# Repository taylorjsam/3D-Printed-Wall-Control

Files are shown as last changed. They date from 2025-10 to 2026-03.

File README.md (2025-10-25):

🛠️ Custom Tool Hangers for Wall Control Pegboard

This repository contains a growing collection of 3D-printable custom tool holders designed specifically for Wall Control pegboard systems (metal pegboard with slotted mounting holes). These hangers are tailored for various tools and accessories — from calipers and screwdrivers to highly specific tool geometries.

⸻

📁 Folder Structure

Metal Small WC Hook Hangers/

These models are designed to use the small metal Wall Control hooks (10-HS-001) that are inserted into the back of the print. The holder portion is 3D-printed and provides the form-fitting rest or clamp for the specific tool:
	•	Ideal when you want the strength and reliability of steel engagement with the board.
	•	Faster print time since hooks are not printed.
	•	Just insert the metal hook into the designated cavity in the print and it should snap into place.

These are perfect for medium to heavy-weight tools.

⸻

Printed Snap Hook Hangers/

These models are designed to use the 3D-printable hook inserts, allowing for fully printed hangers:
	•	Current Version: Gen 4
	•	Toolless snap-in installation.
	•	Injection slot included for glue if additional reinforcement is desired.
	•	Zero-clearance fit to minimize movement once mounted.
	•	Optimized to align tightly within the Wall Control slot geometry.

These are perfect for lightweight to medium-weight tools where full-print integration makes sense.

⸻

🧰 Tool Compatibility

Each tool holder is generally named for the tool it fits, such as:
	•	Park Tool HMR-4
	•	Olsa Flat Pick 3pc
	•	Vessel Megadora 6pc
	•	Caliper Holder (generic)
	•	Wera Hex Plus Allen Set
	•	Knipex 250mm Pliers Wrench

Some holders are generic and multipurpose (e.g., caliper or utility hangers), while others are precision-contoured for exact fits based on STL scans or manual measurements.

⸻

🖨️ Print Recommendations
	•	Primary Material: PETG (Alternatives: PLA+ or ABS)
	•	Nozzle: 0.4 mm
	•	Layer Height: 0.2 mm
	•	Infill: 25%
	•	Walls (Perimeters): 4
	•	Top/Bottom Solid Layers: 4
	•	Supports: Not required (all parts are designed to be support-free)
	•	Orientation: All files are provided in the correct print orientation, but can be rotated if needed.

⸻

🔩 Assembly Notes
	For Printed Snap Hook versions:
	•	Insert the snap hooks into the back of the tool holder — they lock in place via compression and geometry. (Once inserted hook is NOT removable from holder)
	•	Optionally inject a small amount of superglue or epoxy through the glue port.
	•	Thumb tab at the bottom allows for easy installation and removal from wall.
	For Metal WC Hook versions:
	•	Simply press the Wall Control metal hook into the back cavity until fully seated.
	•	Hook is removable but holders are designed to allow installation onto the wall without removal
	Note about warping: On some printers or with certain materials, the longer pieces may be prone to warping. To address this, I’ve included hook mounts both near the center and near the edges. Only two hooks are recommended for these pieces with 4 placement options. If no warping is present, I recommend using the outer mounts as they provide slightly stronger support. However, if any warping is observed, use the inner mounts instead. Attempting to use the outer mounts with a warped piece may shear off the hooks, as they cannot be inserted straight when the part is bent.

⸻

🙌 Contributions

I’m actively refining existing holders and designing new ones as I add tools to my collection. The Gen 4 snap hook system is the most current and reliable release — featuring tight tolerance fits, toolless installation, and optional glue injection points for reinforcement. I am also adding need tools as I acquire them and as I have time.

Got a tool you’d like a hanger for? Submit a request or fork the repo and contribute your own design! If you’re submitting a pull request, please make sure to test the holder with the actual tool first — the goal is to keep all shared designs accurate, functional, and ready for real-world use without modification.

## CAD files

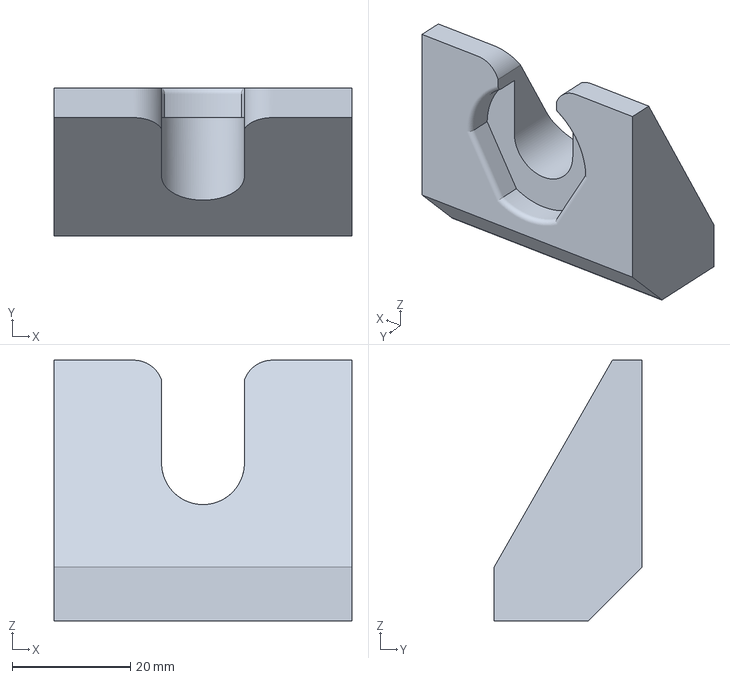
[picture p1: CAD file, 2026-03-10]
Gen 4 Hook.3mf
50.4 x 25.0 x 44.1 mm

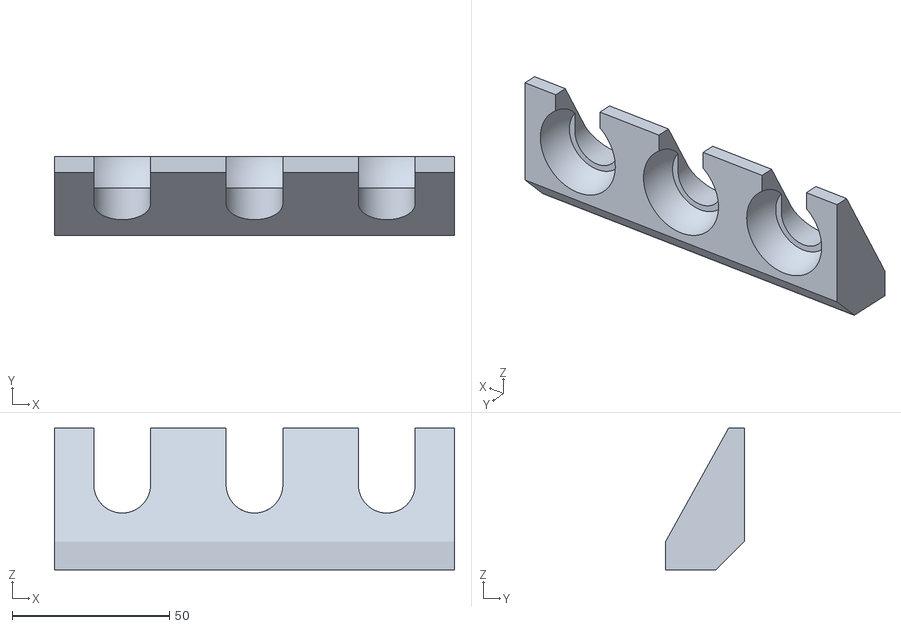
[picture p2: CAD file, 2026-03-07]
Printed Snap Hook Hangers/DeWalt/DeWalt 3pc Chisel.stl
127.0 x 25.0 x 45.1

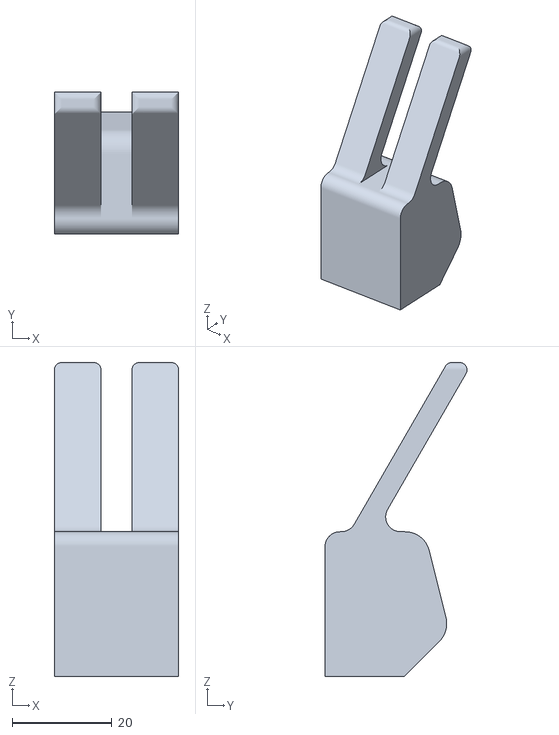
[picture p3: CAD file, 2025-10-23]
Printed Snap Hook Hangers/Doyle/Doyle soft-jaw Pliers PH.stl
25.0 x 28.5 x 63.1

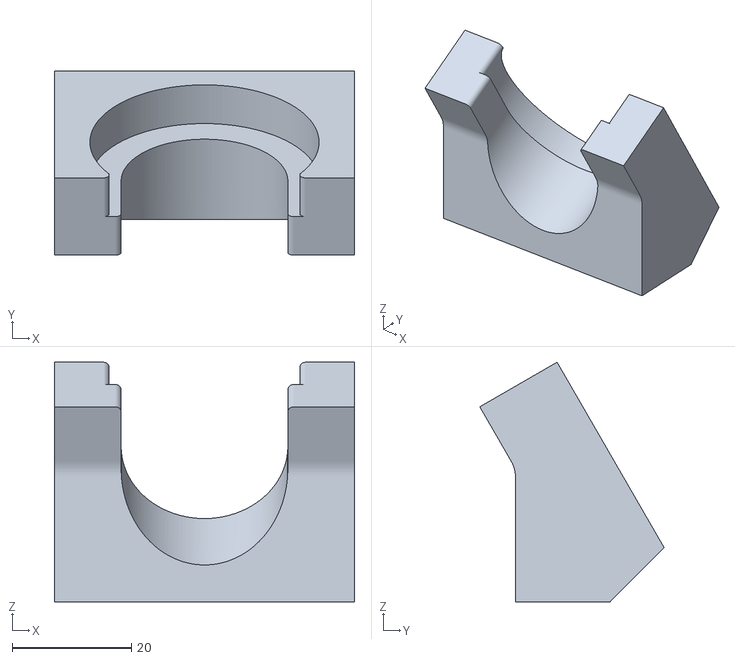
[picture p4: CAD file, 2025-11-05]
Printed Snap Hook Hangers/Engineer/Engineer DR-54 v1 PH.stl
50.4 x 31.0 x 40.3

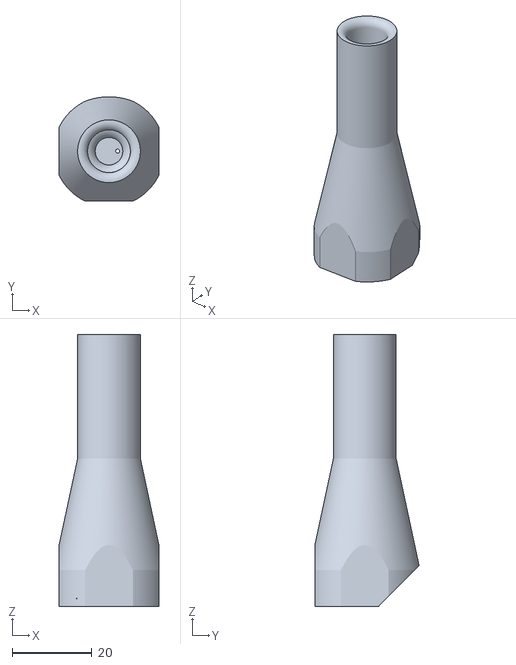
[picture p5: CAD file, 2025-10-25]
Printed Snap Hook Hangers/Finish Line/Finish Line Grease Gun PH.stl
25.0 x 26.1 x 68.1

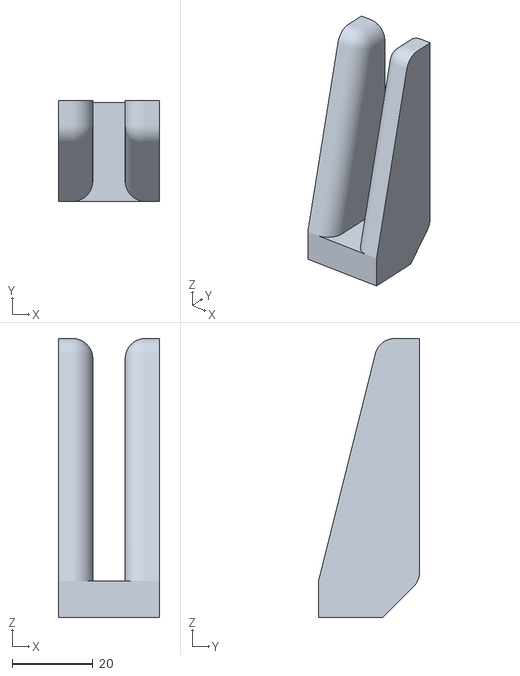
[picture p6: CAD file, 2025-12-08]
Printed Snap Hook Hangers/Generic/Adjustable Wrenches/Adjustable Wrench 8mm (vert) PH.stl
25.0 x 25.0 x 69.1

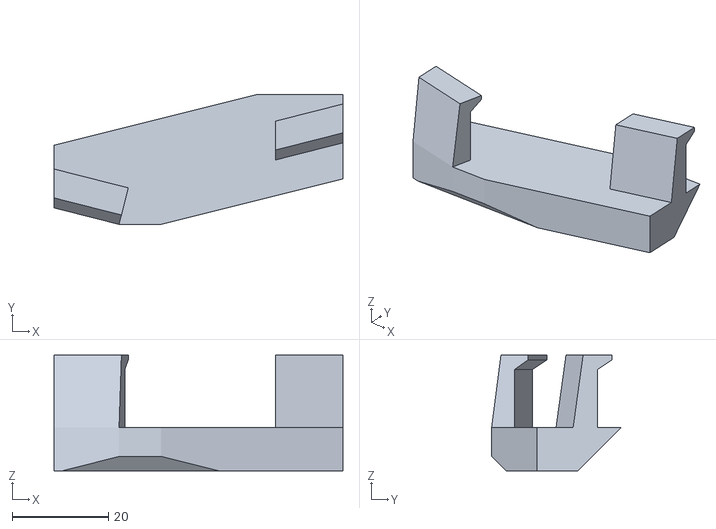
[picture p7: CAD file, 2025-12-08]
Printed Snap Hook Hangers/Generic/Calipers (deep) PH.stl
60.0 x 26.9 x 24.1

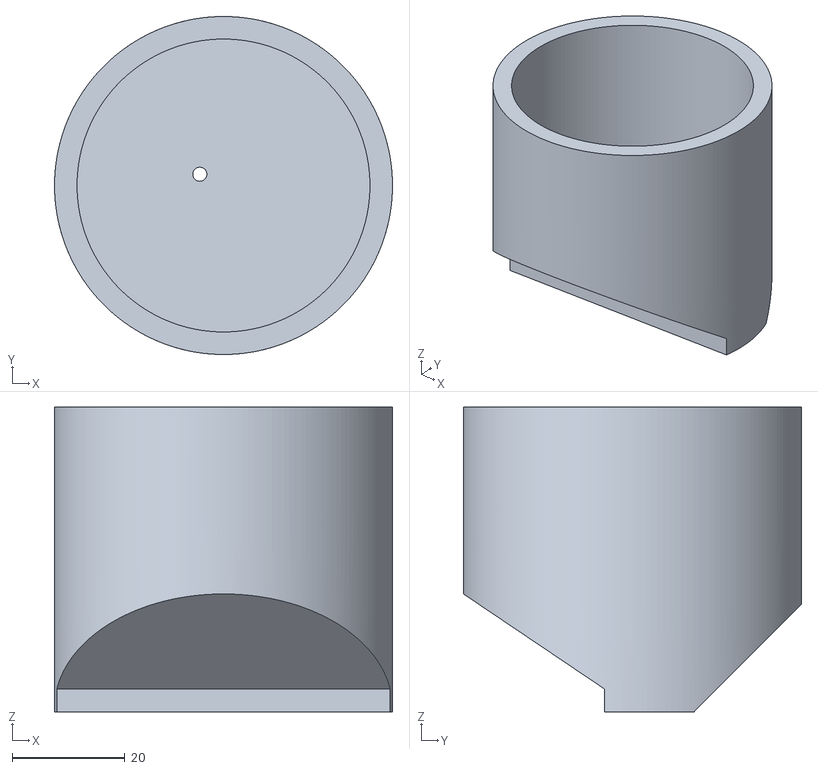
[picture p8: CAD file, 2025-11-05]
Printed Snap Hook Hangers/Generic/Hammers (hold by head face)/51.5mm Hammer PH.stl
60.0 x 60.0 x 54.1

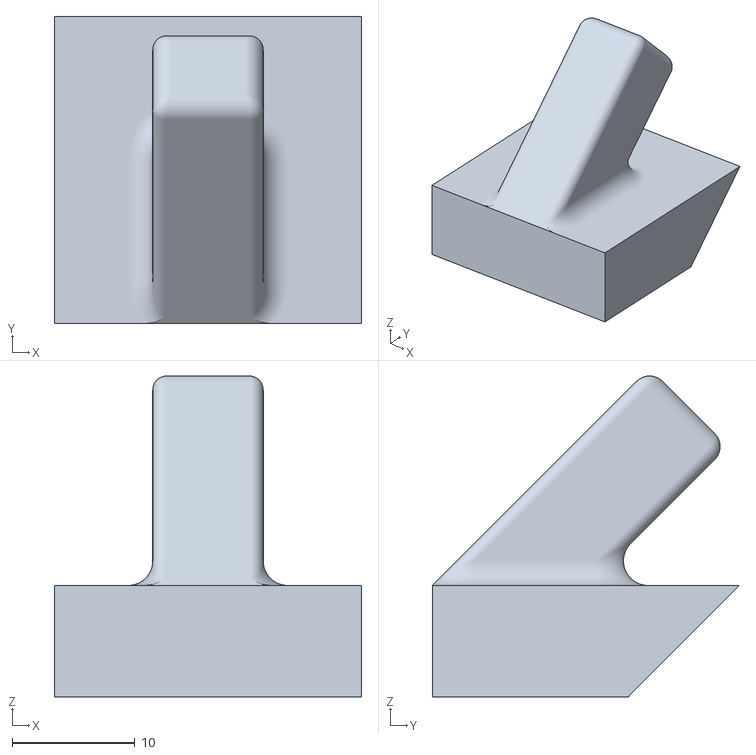
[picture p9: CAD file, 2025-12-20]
Printed Snap Hook Hangers/Generic/Socket Drive Accessories/1x 3:8 Drive Male.stl
25.0 x 25.0 x 26.1

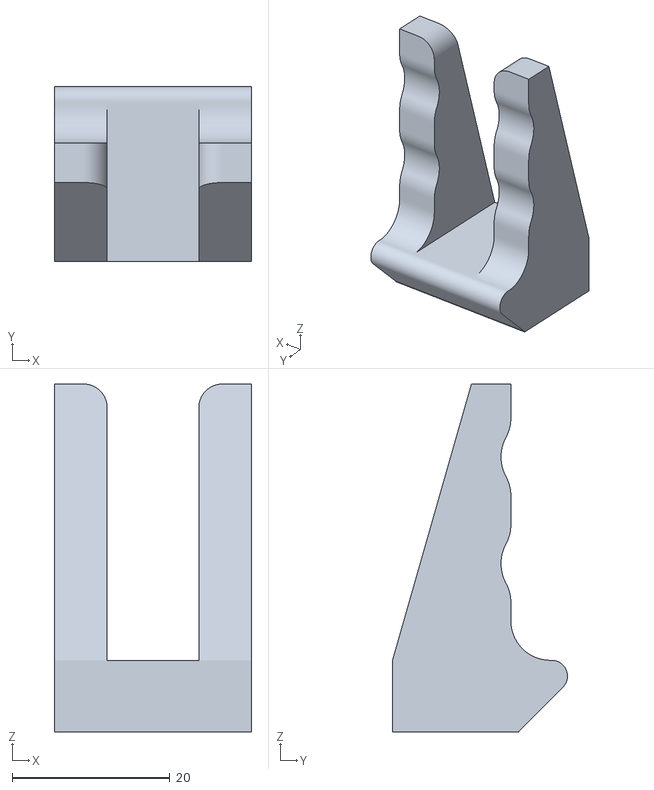
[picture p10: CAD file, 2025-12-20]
Printed Snap Hook Hangers/Icon/Icon Long Nose Slip Joint Pliers.stl
25.0 x 22.2 x 44.1

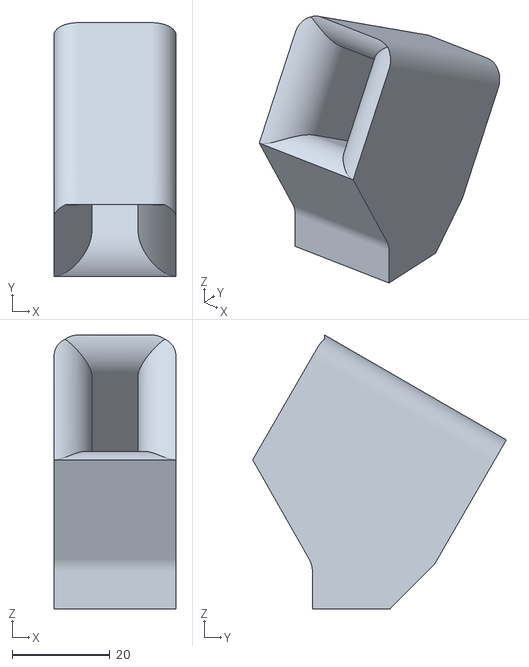
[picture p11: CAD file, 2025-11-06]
Printed Snap Hook Hangers/Igance/Igance P6 Pro (vert) PH.stl
25.0 x 52.0 x 56.2

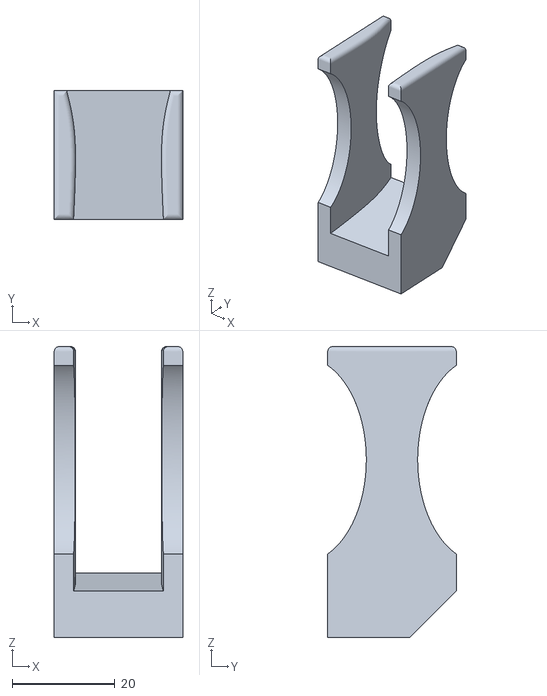
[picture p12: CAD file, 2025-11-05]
Printed Snap Hook Hangers/Knipex/Knipex 2612200 (vert) PH.stl
25.0 x 25.0 x 56.6

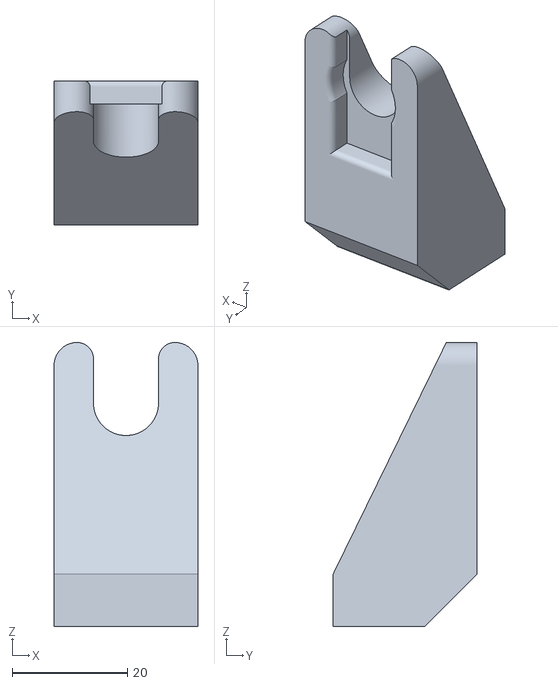
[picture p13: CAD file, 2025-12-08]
Printed Snap Hook Hangers/Milwaukee/Milwaukee Hamerdrill Handle PH.stl
25.0 x 25.0 x 49.3

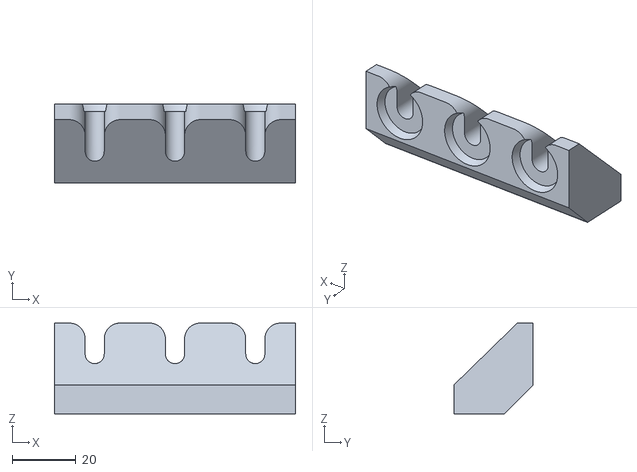
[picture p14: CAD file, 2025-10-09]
Printed Snap Hook Hangers/Olsa/Olsa Flat Pick 3pc PH.stl
75.8 x 25.0 x 28.6

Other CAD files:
Printed Snap Hook Hangers/Park Tool/Park Tool CT-3 (vert) PH.stl
Printed Snap Hook Hangers/PB Swiss/PB Swiss 1255 MR PH.stl
Printed Snap Hook Hangers/Pedro's/Pedros Cable Cutters (vert)PH.stl
Printed Snap Hook Hangers/Rock Shox/Rock Shox Shock Pump SH.stl
Gen 4 Hook.stl
Old Hooks/Gen 3 Hook.stl
Printed Snap Hook Hangers/Gedore/Gedore sg Ratcheting Screwdriver.stl
Printed Snap Hook Hangers/Generic/Adjustable Wrenches/Adjustable Wrench 10mm (vert) PH.stl
Printed Snap Hook Hangers/Generic/Adjustable Wrenches/Adjustable Wrench 9mm (vert) PH.stl.stl
Printed Snap Hook Hangers/Generic/Angle Grinder (wrench) PH.stl
Printed Snap Hook Hangers/Generic/Angle Grinder Disc Holder.stl
Printed Snap Hook Hangers/Generic/Bic Ligher Holder PH.stl
Printed Snap Hook Hangers/Generic/Calipers (shallow) PH.stl
Printed Snap Hook Hangers/Generic/Flat Hook 25mm at 45deg PH.stl
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

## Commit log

2025-10-04 First dump of completed files
    [Holder 10mm (chamfered) v2.stl, Holder 10mm (cylinder) v2.stl, Holder 10mm (flat) v2.stl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]
2025-10-05 snap hooks dump
    [Generic Calipers PH.stl, Park Tool CC-3.2 PH.stl]
2025-10-06 10/5 dump
    [Park Tool PW-3 WC.stl, Park Tool TM-1 PH.stl]
2025-10-07 dump 10/6
    [Park Tool 1in Hex Holder.stl, Park Tool CCP-22.stl, Park Tool CCW-5.stl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]
2025-10-07 organizing + 10/6 dump p2
    [Generic Calipers PH.stl, Park Tool 1in Hex Holder PH.stl, Park Tool CCW-5 PH.stl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]
2025-10-08 Gen 3 plastic hook updates
    [Generic Calipers PH.stl, Park Tool 1in Hex Holder PH.stl, Park Tool CC-3.2 PH.stl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]
2025-10-09 10/8 dump
    [Olsa Flat Pick 3pc PH.stl, SK 8in Shears.stl, Spoke Pick Holder PH.stl]
2025-10-09 10/8 fixes
    [Olsa Flat Pick 3pc PH.stl, SK 8in Shears.stl]
2025-10-10 10/9 dump/updates
    [Calipers PH.stl, Flat Hook 25mm at 45deg PH.stl, Generic Calipers PH.stl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]
2025-10-16 Gen 4 Hook + organization + readme
    [Calipers PH.stl, Flat Hook 25mm at 45deg PH.stl, Gen 3 Hook.stl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]
2025-10-18 10/17 dump + PH organization
    [Bic Ligher Holder.stl, Olsa Flat Pick 3pc PH.stl, PB Swiss 4pc PH-PZ.stl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]
2025-10-18 NP-6 fix
    [Park Tool NP-6 PH.stl]
2025-10-18 megadora add on
    [Megadora P0-S4 add-on PH.stl]
2025-10-19 Add PH to old designs
    [Park Tool BBT-9 PH.stl, Park Tool MLP-1.2 PH.stl, Park Tool PH-T1.2 v1 (t30-t40).stl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]
2025-10-20 Create Park Took ATD-1.2.stl
2025-10-23 10/22 dump
    [Calipers (deep) PH.stl, Calipers (shallow) PH.stl, Doyle soft-jaw Pliers PH.stl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]
2025-10-24 Milwaukee + SK dump
    [Milwaukee 48-22-3406 PH.stl, Milwaukee 48-22-3407 PH.stl, Milwaukee 48-22-3409 PH.stl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]
2025-10-24 PH swiss 4x snap hook update
    [PB Swiss 4pc PH-PZ PH.stl, PB Swiss 4pc PH-PZ.stl, PB Swiss 6pc Flat.stl]
2025-10-24 move mount pos wera 4x sd
    [Wera VDE Screwdrivers 4pc MMSS.stl]
2025-10-25 10/25 dump
    [31.5mm Hammer PH.stl, 33mm Hammer PH.stl, 51.5mm Hammer PH.stl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]
2025-11-05 11/4 dump
    [51.5mm Hammer PH.stl, 52.5mm Hammer PH.stl, Engineer DR-54 v1 PH.stl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]
2025-11-06 11/5 dump + name updates
    [Igance P6 Pro (vert) PH.stl, Knipex 13728 (vert) PH.stl, Knipex 2502140 (vert) PH.stl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]
2025-12-08 12/7 dump
    [10mm (chamfered) v2.stl, 10mm (cylinder) v2.stl, 10mm (flat) v2.stl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]
2025-12-08 Update Calipers (deep) PH.stl
    [Calipers (deep) PH.stl]
2025-12-18 12/18 Dump
    [Bernzomatic Firepoint Creator Tool.stl, CooBeast 1:4 Digital Torque Wrench.stl, M18 Upright v4 (angled 27.5).stl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]
2025-12-20 12/19 dump
    [1:4 Drive Extension.stl, 1x 1:2 Drive Male.stl, 1x 1:4 Drive Male.stl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]
2026-03-05 3/4 dump
    [DeWalt 3pc Chisel.stl, Starrett 18-C.stl]
2026-03-07 3/6/26 dump
    [DeWalt 3pc Chisel.stl]
2026-03-09 3/9/26 dump
    [Gedore sg Ratcheting Screwdriver.stl, Snap On Ratcheting Screwdriver PH.stl, Tekton SHM04109 ph.stl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]
2026-03-10 wera updates
    [Gen 4 Hook.3mf, Wera 074710 (Adjustable Torque) PH.stl, Wera VDE Screwdrivers 2pc LM.stl]
